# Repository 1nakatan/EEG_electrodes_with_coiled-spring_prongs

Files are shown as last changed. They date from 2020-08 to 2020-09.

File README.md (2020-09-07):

# EEG_electrodes_with_spring_prongs

This repository is based on the following paper.

[M. Kimura, S. Nakatani, S.-I. Nishida, D. Taketoshi, and N. Araki, “3D Printable Dry EEG Electrodes with Coiled-Spring Prongs,” Sensors, vol. 20, no. 17, p. 4733, Aug. 2020.](https://www.mdpi.com/1424-8220/20/17/4733/htm)

Four stl files are available in this repository: 
- [spring.stl][1]
- [cover.stl][2]
- [spring_support.stl][3]
- [cover_support.stl][4]

[spring.stl][1] is a main material and [cover.stl][1] is a supplementary material that covers the prongs of the spring electrode. The stl files named ***_support.stl are included with the support material needed to print correctly on an SLA type 3D printer.
This electrode is designed for [Ultracortex Mark IV, OpenBCI](https://docs.openbci.com/docs/04AddOns/01-Headwear/MarkIV). They will print correctly if you use the equipment and print settings described in our paper.

# How To Print
The following is the procedure for making the electrodes, which are available to the public:
1. Download the [spring _support.stl][3] and [cover_support.stl][4] files.
2. Slice and print them with the print settings and resin shown in the paper. 
3. Wash the printed electrode with IPA and cut off the support with a nipper or similar tool referring to [spring.stl][1]. After that, allow the resin to cure sufficiently until it turns light blue.
4. Apply conductive paint all over the surface as shown in the figure (in the picture, a part of the side of the electrode is removed).
5. Attach the printed electrodes to the blue unit to which the stock electrodes were attached with the screws.

electrodes print settings Slice and print
PAINT Cpnductive paste painting

# CAUTION
It is very rare to succeed in the first printing. If you fail, try again with different print settings (such as exposure time or bottom exposure time) and resin temperature.
The published electrode structures, dimensions and print settings are optimized for  [blu by Siraya Tech](https://siraya.tech/products/blu-by-siraya-tech-for-lcd-resin-printers-1kg). If the exposure time is too long, the print may become too thick not to work spring as shown below.

ERROR Exposure time is too long

[1]:https://github.com/1nakatan/EEG_electrodes_with_coiled-spring_prongs/blob/master/spring.stl
[2]:https://github.com/1nakatan/EEG_electrodes_with_coiled-spring_prongs/blob/master/cover.stl
[3]:https://github.com/1nakatan/EEG_electrodes_with_coiled-spring_prongs/blob/master/spring_support.stl
[4]:https://github.com/1nakatan/EEG_electrodes_with_coiled-spring_prongs/blob/master/cover_support.stl

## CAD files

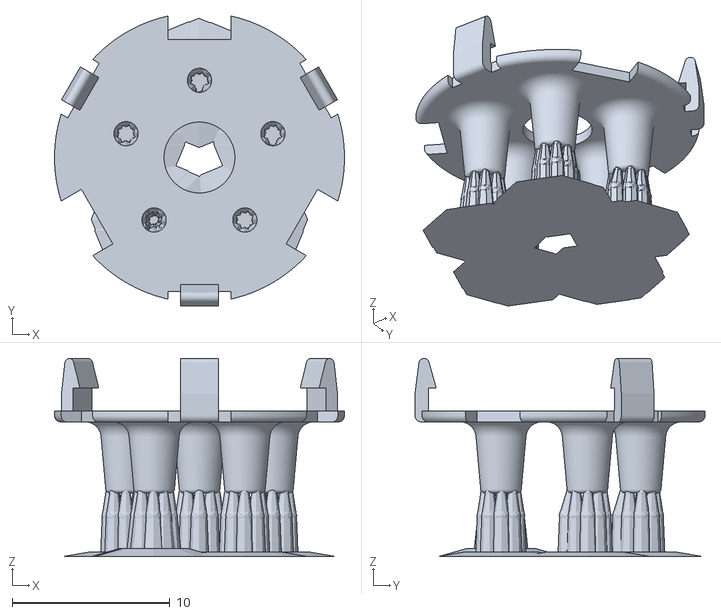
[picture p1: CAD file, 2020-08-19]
cover_support.stl
18.4 x 18.4 x 12.6

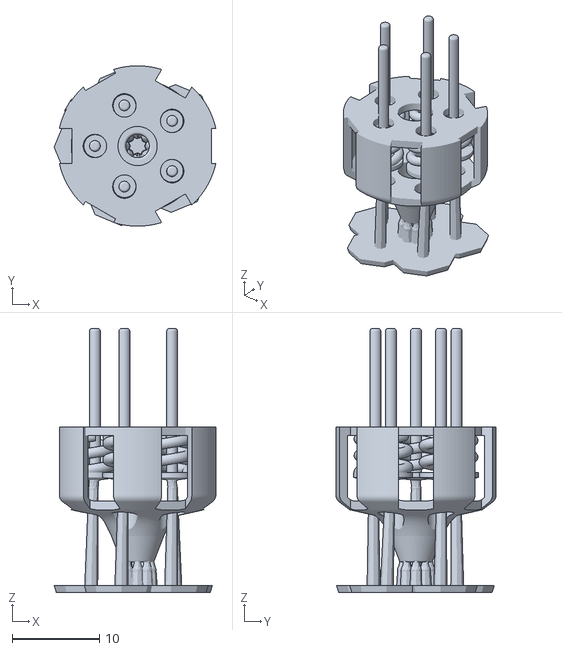
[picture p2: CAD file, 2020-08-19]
spring_support.stl
18.6 x 18.4 x 30.3

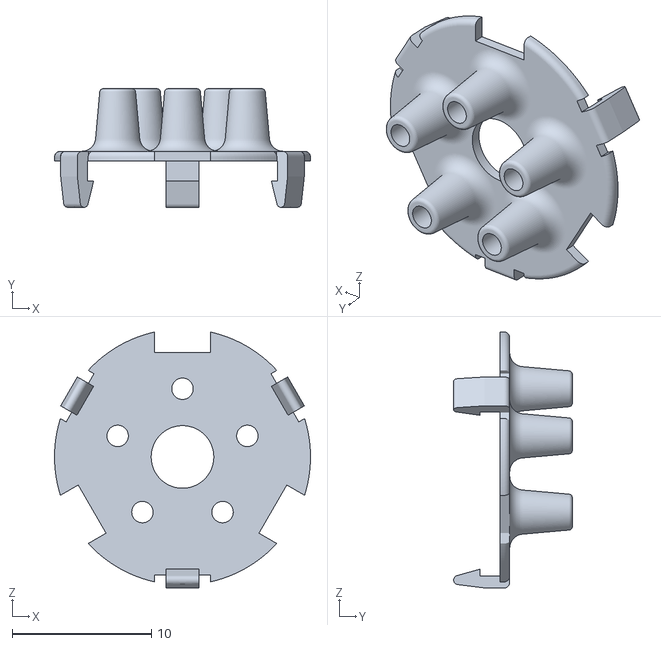
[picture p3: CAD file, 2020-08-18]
cover.stl
18.4 x 8.53 x 18.4

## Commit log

2020-08-18 stl files
    Stl files were added
    [cover.stl]
2020-08-19 fix and add files
    [cover_support.stl, spring_support.stl]
2020-08-20 Update README.md
    add how to print
2020-08-20 Update README.md
    add link to stl files
